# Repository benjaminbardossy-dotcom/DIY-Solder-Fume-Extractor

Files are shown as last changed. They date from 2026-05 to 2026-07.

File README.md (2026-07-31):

# DIY Solder Fume Extractor
Banner

# Why Make Your Own? / Why I Made This
While looking for a good solder fume extractor online, I found that many of the cheaper solder fume extractors sold online were still relatively expensive for the purpose they served. The other major issue I found was that many weren't actually able to effectively remove many of the harmful particles created from soldering. These fume extractors often only feature an activated carbon filter, making them ineffective at removing a lot of the harmful particles associated with soldering. Other than the filter media, there's also no guarantee of the strength of the fan, or lifetime of the filter. Once either of those die, there's no telling how costly or hard it will be to replace. 
### But Why is Activated Carbon Ineffective?
While activated carbon is great at removing the smell associated with soldering, it falls flat when attempting to filter out the smaller harmful particles. Activated carbon mainly removes volatile organic compounds(VOCs), which are responsible for the smell associated with soldering. However, activated carbon is not nearly as effective at trapping other small particles created from soldering, since it cannot reliably catch them.

### My Solution
Create your own! Creating a good fume extractor shouldn't be hard or expensive, which is why I decided to make this project.

If you want a full cost breakdown, check out the spreadsheet I made for this project [here](https://docs.google.com/spreadsheets/d/1kI0-QvfijKjpn8jp-Lh3tqiNpf6TtSSo3WHpc60xSvA/edit?gid=0#gid=0)\
To watch a short demo, click on this link: [Youtube](https://www.youtube.com/watch?v=zQ6AQj5pzdw)

# The Design

## The filter
### Pre-Filter -> HEPA -> Activated Carbon
For my fume extractor, I decided to add a multi stage filtration system since I found this to be the best option for both filtration and longevity. The media is arranged as shown above. The pre-filter acts as a barrier to catch large particles which may stick to and clog the finer filter media such as the HEPA filter. This extends the lifetime of both the fan and other filter media. The HEPA filter serves as the solution to trapping finer particles. It effectively filters out 99.97% of particles with a size of 0.3 microns([source](https://www.epa.gov/indoor-air-quality-iaq/what-hepa-filter)), and even filters out smaller particles(0.3 microns is just the benchmark for measuring effectiveness). I still included an activated carbon layer, since it is still best to also remove any remaining VOCs.

## The Case
Before creating my case, I thought of what I wanted in a fume extractor. I wanted an easily printed case with internals made from components readily available to the average hobbyist, and I wanted it to be cheaper than the extractors available online. To do so I created a case which prints in separate parts and is attached by M2 inserts and screws, a top which screws off to reveal both the filter media and pc fan, and an open source design which can be easily modified to fit any hobbyist's components. As for the price, I managed to keep it at a cost of just under $22 CAD for one build. 

## The Working Build
avgk1a

## How It Fits Together
Side / Front:\
Side_edited (1)
Front_edited\
Back / Top:\
Back_edited (1)
Top_edited

## Wiring Diagram


# Creating Your Own
This design was made to be easily replicable for the average hobbyist, and if you're interested in creating your own, I created this guide to help at every step. This project is intended to be made when you have old components laying around, in this case a used computer fan. This project is cheapest when using a used fan. If you have a used fan you want to use, but it doesn't fit the dimensions(80mm*80mm), I recommend downloading the native CAD files for Fusion 360 which can be found under the folder "Fusion 360 File", and editing the dimensions of the box and exporting your own STLs.

1. Gather the Necessary Files(All files / folders referenced can be found at the top of this repo)
   - Download the STL files found in folder Fume Extractor STLs
3. Gather the Materials
   - Order any missing components from the BOM list below
   - Upload the STL files to a 3D printing software of your choice and print the case, OR alternatively order the STL files to a vender which offers 3D printing services if you don't have access to a 3D printer
4. Assemble
   - Gather the needed parts
   - Use a solder pen with the M2 insert attachment to heat up the inserts and place them into their designated spots on the model(see [how it fits together](#how-it-fits-together))
   - Snap switch into place in its designated spot
   - Cut the head off of the 12V adapter to expose the positive and negative wires
   - Strip the ends of the positive and negative wires of the fan
   - Solder as shown in the [wiring diagram](#wiring-diagram)
   - Place objects as shown in the design photo
   - Use M2 nuts to secure fan
   - Use M2 screws to screw the case into place
   - Place filter media as shown: Pre-filter -> HEPA filter -> Activated carbon filter
   - Screw top on

# BOM
[*View Bill of Materials (CSV)](./fume_extractor_BOM.csv)
| Material | Quantity | Cost($CAD) | Link |
| --- | --- | --- | --- |
| M2 Screws| 12 | 0.26 | https://www.amazon.ca/780Pcs-Screws-Metric-Washers-Steel-Black/dp/B0D7QCS5FL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 |
| M2 Nuts | 4 | 0.09 | https://www.amazon.ca/780Pcs-Screws-Metric-Washers-Steel-Black/dp/B0D7QCS5FL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 |
| M2 Heat Inserts | 8 | 1.12 | https://www.amazon.ca/HANGLIFE-Heat-Set-Threaded-Components-Soldering/dp/B0D477R64K?th=1 |
| PC Fan | 1 | 6.53 | https://www.aliexpress.com/item/1005002971846100.html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 |
| Prefilter | 38.40cm^3 | 0.05 | https://www.aliexpress.com/item/1005005513088209.html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 |
| HEPA Filter | 2 | 2.52 | https://www.aliexpress.com/item/1005002687133564.html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 |
| Activated Carbon Filter | 32.00cm^3 | 0.003 | https://www.aliexpress.com/item/32789944517.html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|
| Potentiometer | 1 | 0.98 | https://www.aliexpress.com/item/1005006143559414.html?spm=a2g0o.order_list.order_list_main.80.261d1802WHEldB |
| Electronic Switch | 1 | 0.68 | https://www.aliexpress.com/item/1005008778176373.html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 |
| 12V 1A Adapter | 1 | 6.01 | https://www.aliexpress.com/item/1005001731366424.html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 |
| 3D Printer Filament | 84.37g | 1.69 | https://www.amazon.ca/ELEGOO-Filament-Dimensional-Accuracy-Printers/dp/B0D421Q2Q2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 |
| Heat Shrink | 2 | 0.80 | https://www.aliexpress.com/item/1005008895688869.html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 |

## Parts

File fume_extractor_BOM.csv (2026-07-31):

Material | Quantity | Cost($CAD) | Link
M2 Screws | 12 | 0.26 | https://www.amazon.ca/780Pcs-Screws-Metric-Washers-Steel-Black/dp/B0D7QCS5FL
M2 Nuts | 4 | 0.09 | https://www.amazon.ca/780Pcs-Screws-Metric-Washers-Steel-Black/dp/B0D7QCS5FL
M2 Heat Inserts | 8 | 1.12 | https://www.amazon.ca/HANGLIFE-Heat-Set-Threaded-Components-Soldering/dp/B0D477R64K?th=1
PC Fan | 1 | 6.53 | https://www.aliexpress.com/item/1005002971846100.html
Prefilter | 38.40cm^3 | 0.05 | https://www.aliexpress.com/item/1005005513088209.html?mp=1
HEPA Filter | 2 | 2.52 | https://www.aliexpress.com/item/1005002687133564.html?mp=1
Activated Carbon Filter | 32.00cm^3 | 0.003 | https://www.aliexpress.com/item/32789944517.html?curPageLogUid=XRfYtDNrAWy3
Potentiometer | 1 | 0.98 | https://www.aliexpress.com/item/1005006143559414.html
Electronic Switch | 1 | 0.68 | https://www.aliexpress.com/item/1005008778176373.html?p4p_pvid=20260512143655131318433995970003058183_3
12V 1A Adapter | 1 | 6.01 | https://www.aliexpress.com/item/1005001731366424.html?src=google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
3D Printer Filament | 84.37g | 1.69 | https://www.amazon.ca/ELEGOO-Filament-Dimensional-Accuracy-Printers/dp/B0D421Q2Q2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
Heat Shrink | 2 | 0.80 | https://www.aliexpress.com/item/1005008895688869.html?curPageLogUid=DUcnDSfQfAhJ

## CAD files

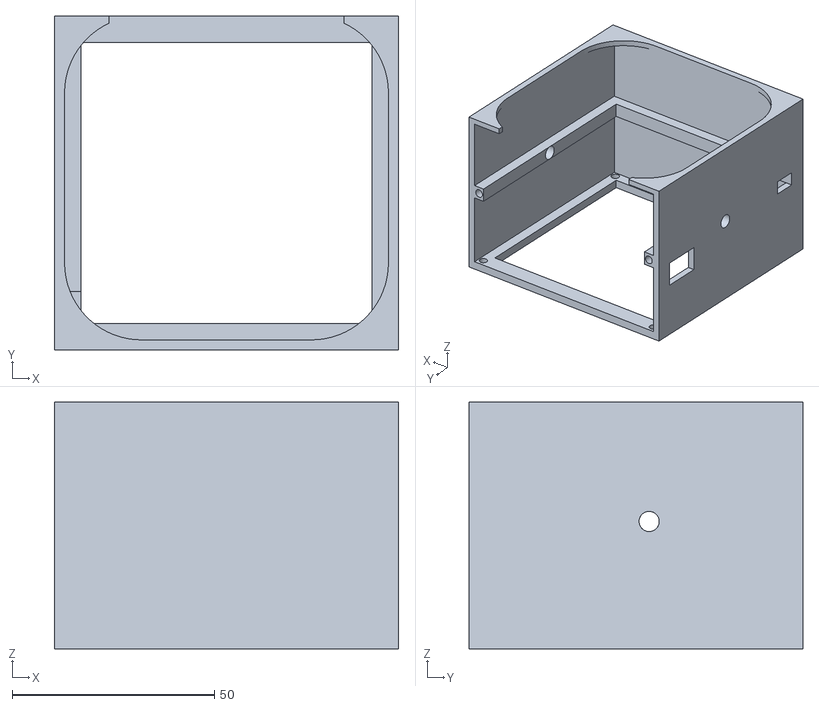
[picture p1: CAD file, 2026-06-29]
Fume Extractor STLs/Body.stl
85.0 x 82.5 x 61.0

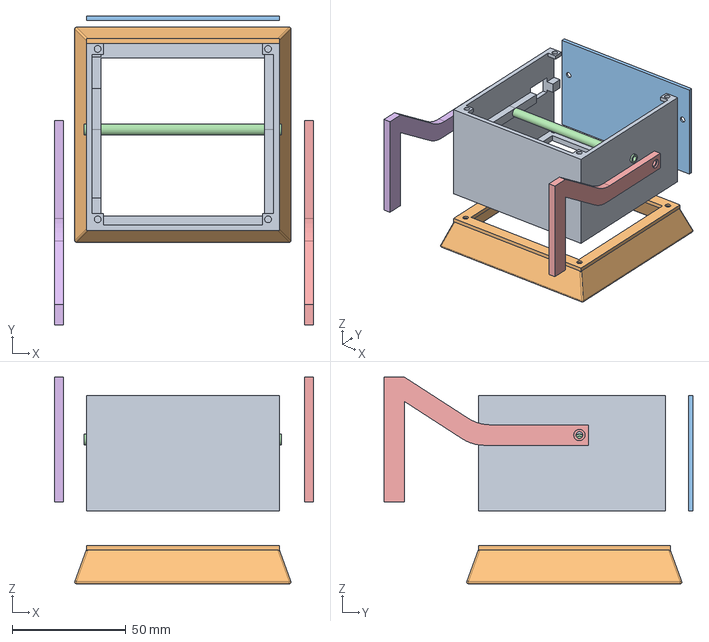
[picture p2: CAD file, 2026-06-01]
solder_fume_extractor.step
114.0 x 136.0 x 91.0 mm

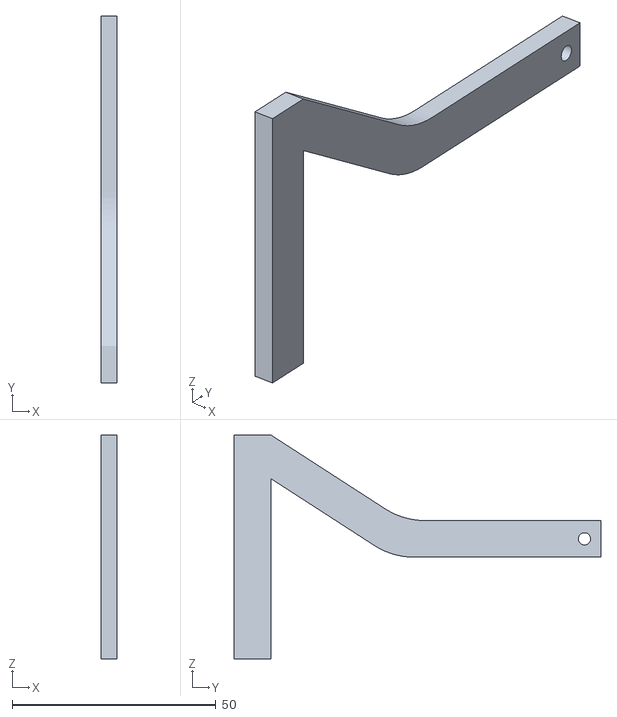
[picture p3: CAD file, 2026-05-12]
Fume Extractor STLs/Leg_L.stl
4.00 x 90.0 x 55.0

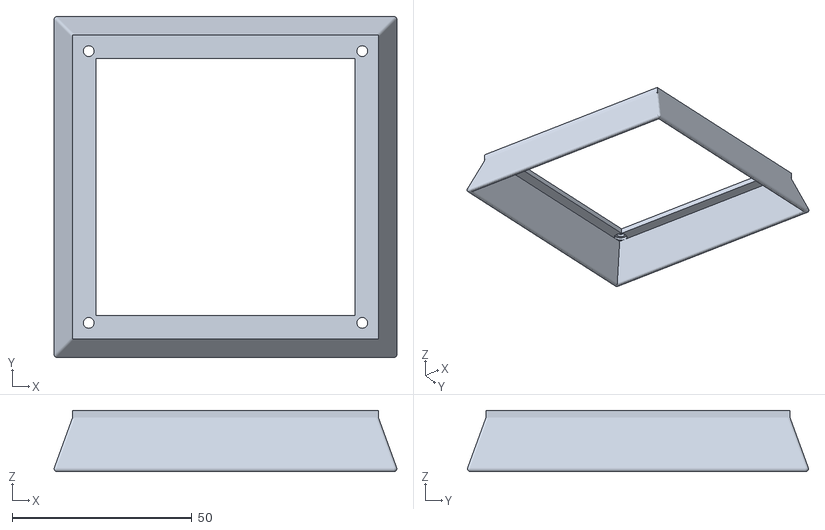
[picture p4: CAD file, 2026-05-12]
Fume Extractor STLs/Head.stl
95.2 x 94.7 x 17.0

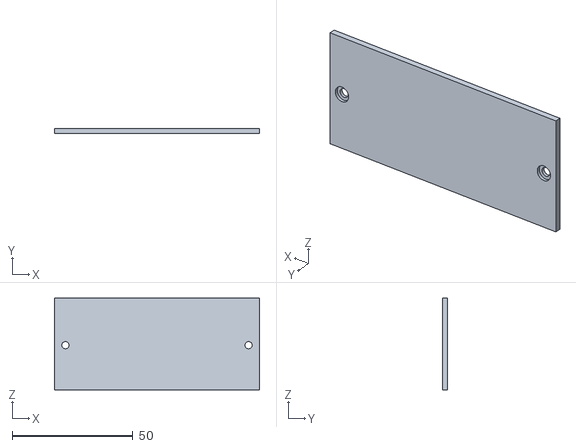
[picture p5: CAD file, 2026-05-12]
Fume Extractor STLs/Top.stl
85.0 x 2.00 x 38.0

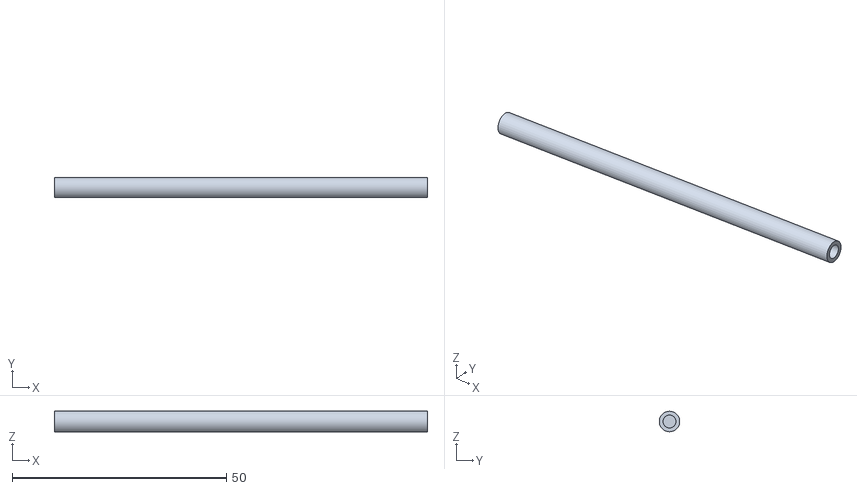
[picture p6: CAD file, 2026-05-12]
Fume Extractor STLs/Pole.stl
87.0 x 4.77 x 4.80

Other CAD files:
Fume Extractor STLs/Leg_R.stl
solder_fume_extractor.f3d

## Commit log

2026-05-17 Rename solder_fume_extractor.f3d to Fusion 360 File/solder_fume_extractor.f3d
    [solder_fume_extractor.f3d]
2026-07-31 Update BOM link format in README
